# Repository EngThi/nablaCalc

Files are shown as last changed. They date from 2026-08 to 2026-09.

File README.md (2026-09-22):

# ∇Calc

A handheld scientific calculator built around an ESP32-S3, featuring a 2.2-inch SPI display, an OV5640 camera for snapping equations, and a custom 4-layer PCB inside a 3D-printed case.

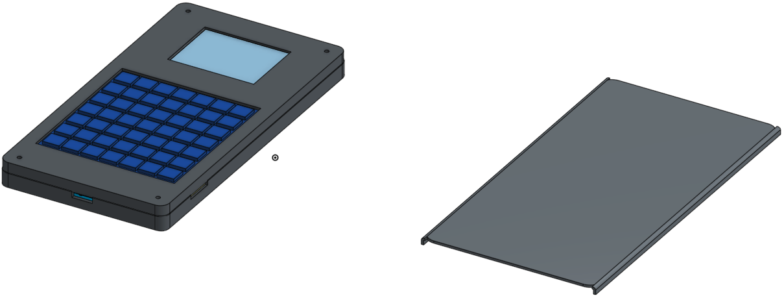
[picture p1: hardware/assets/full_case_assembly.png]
NablaCalc virtual enclosure assembly


## Why I built this

Phones have calculator apps, but pulling out a phone while studying is an immediate distraction. On the other hand, traditional scientific calculators are expensive and lack the modern features and tech we have today.

I wanted to make a dedicated desk tool with modern open hardware (ESP32-S3, USB-C, SPI screen) and physical keys. The camera is tucked behind a sliding shutter just to snap math problems from textbooks or notes when needed.

## Current Status

This is a complete hardware design ready for prototype fabrication:
- **PCB:** Custom 4-layer board (84 × 85 mm) designed in EasyEDA Pro, fully routed and DRC-clean.
- **Case:** Multi-part 3D model designed in Onshape with a sliding camera shutter.
- **Keyboard:** The PCB has the matrix routing and MCP23017 expander for a 7×7 layout. The physical tactile membrane and keymat will be built once the components arrive.
- **Firmware:** ESP-IDF base with I2C and SPI peripheral setup.

## Hardware

- **MCU:** ESP32-S3-WROOM-1-N16R8 (16 MB Flash, 8 MB PSRAM)
- **Display:** 2.2-inch 320×240 TFT LCD (ILI9341 via SPI)
- **Camera:** 5 MP OV5640 autofocus module (DVP) with a mechanical cover
- **Power:** USB-C charging with TP4056 and TPS63001 buck-boost (3.3V rail)
- **Storage:** MicroSD slot (SPI)
- **Keypad:** 7×7 matrix via MCP23017 I2C expander

## First build / prices

I am going with the JLC Top PCBA because I do not have experience soldering the small parts myself. Their minimum gives me five boards and two Top assemblies. I will do the Bottom side later.

| Item | Price (USD) |
|---|---:|
| JLC Top PCBA: 5 PCBs + 2 Top assemblies, with the ESP32-S3 | 86.18 |
| Bottom components for the two boards | 4.43 |
| Battery, camera, display, FPC cables and screws | 24.51 |
| **Funding request, without shipping or taxes** | **115.12** |

The parts list, links and price evidence are in [external parts](hardware/procurement/NablaCalc_External_Parts.csv).

## Links

- [EasyEDA PCB Source](hardware/pcb/source/NablaCalc_PCB.epro2) & [Schematic](hardware/pcb/source/NablaCalc_Schematic.epro2)
- [Fabrication Gerbers & BOM](hardware/pcb/)
- [Onshape 3D Assembly](mechanical/onshape_exports/NablaCalc_Assembly_2.2in_Display.step)
- [Firmware Source](firmware/nabla_firmware/)

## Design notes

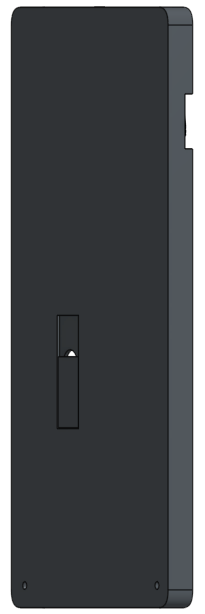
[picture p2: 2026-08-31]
hardware/assets/camera_shutter.png

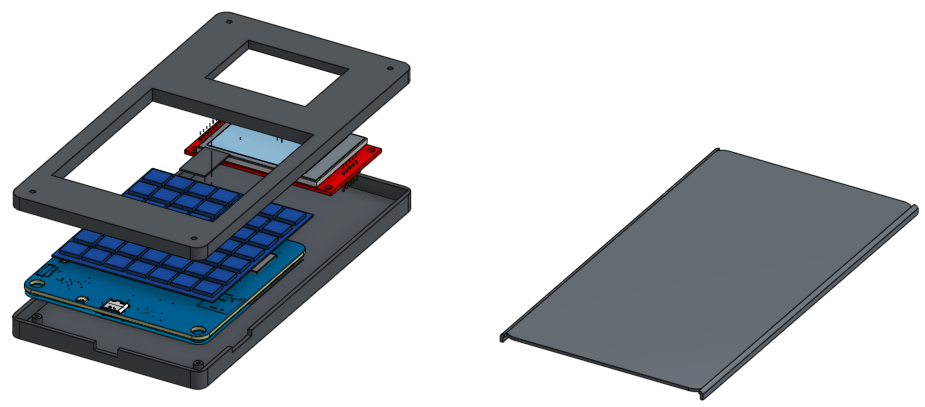
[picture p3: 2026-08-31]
hardware/assets/exploded_view.png

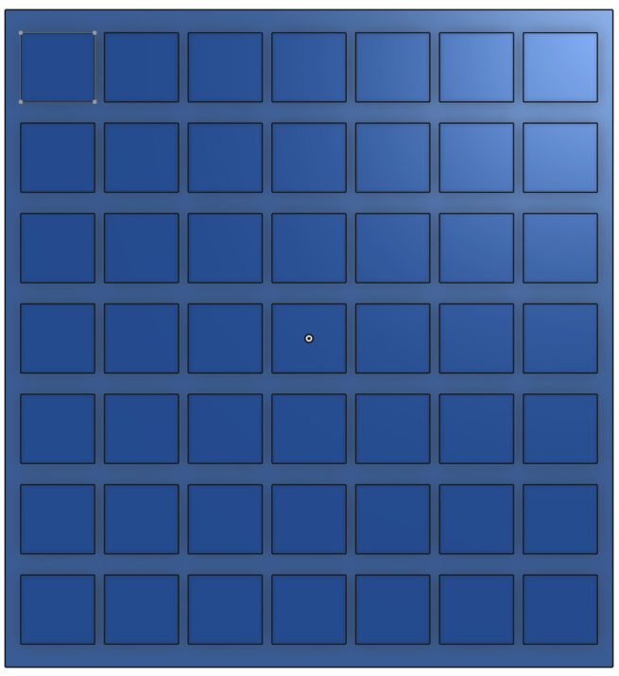
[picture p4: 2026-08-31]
hardware/assets/keypad_case.png

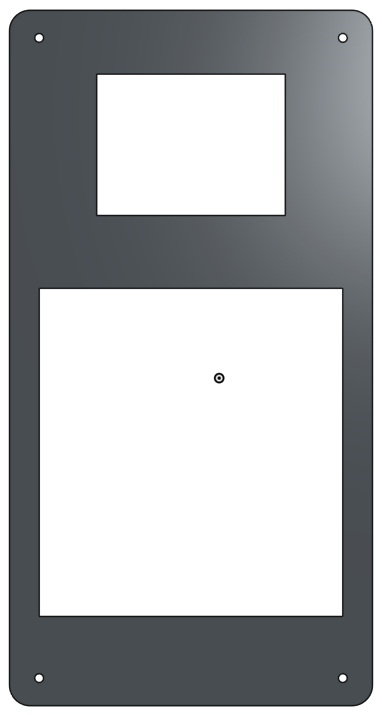
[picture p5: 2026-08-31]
hardware/assets/front_shell_case.png

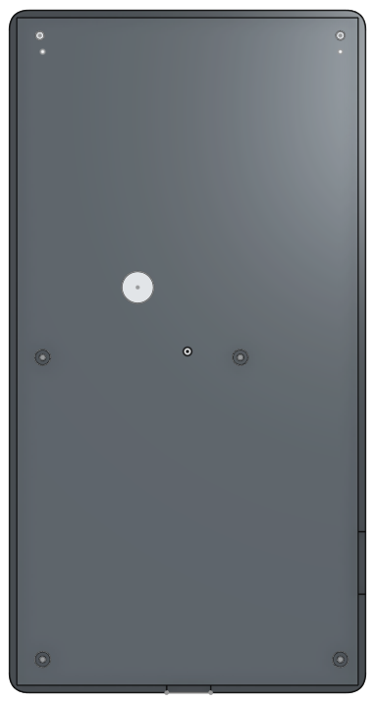
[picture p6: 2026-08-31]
hardware/assets/rear_shell_case.png

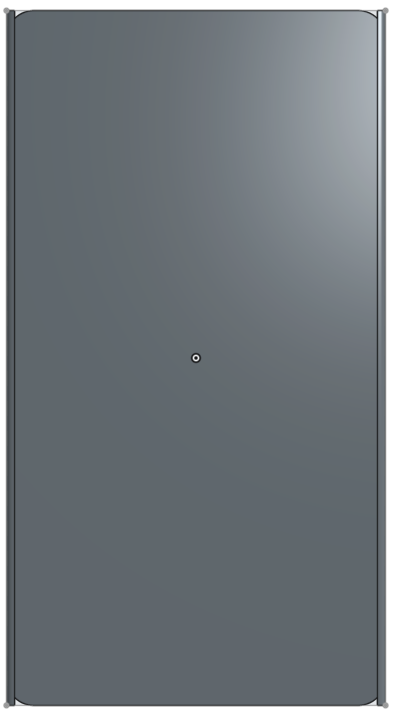
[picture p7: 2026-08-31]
hardware/assets/slide_cover_case.png

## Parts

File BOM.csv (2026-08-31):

Category | Qty | Item | Purchase route | Unit price USD | Line total USD | Included in current request | Status | Source link | Notes
PCB plus Top PCBA | 1 | NablaCalc four-layer PCB with Top SMT | JLCPCB JLCONE quote Y20 | 86.18 | 86.18 | Yes | Confirmed product subtotal | https://jlcpcb.com | Five bare PCBs plus two Top assemblies; includes ESP32-S3 U4.
Bottom-side components | 2 | Manual Bottom population | LCSC | 2.21 | 4.43 | Yes | Reference price for two sets | hardware/procurement/NablaCalc_JLC_LCSC_Only_BOM.csv | For the two JLC Top assemblies.
Battery | 1 | Protected LiPo 1S | Mercado Livre | 6.89 | 6.89 | Yes | Selected | https://www.mercadolivre.com.br/1-peca-503450-37v-com-2-fios-1000mah-5mm-x-34mm-x-50mm/up/MLBU2072595624 | 503450 3.7V 1000mAh; 5 x 34 x 50 mm.
Camera | 1 | RAW autofocus camera | AliExpress | 5.40 | 5.40 | Yes | Selected | https://www.aliexpress.com/item/1005006858943975.html | OV5640 5MP; 24-pin DVP; 68D lens; 78mm FPC.
Display | 1 | SPI LCD module | AliExpress | 6.22 | 6.22 | Yes | Selected | https://www.aliexpress.com/item/33015586094.html | 2.2-inch SPI TFT 320x240; no-touch option.
FPC cables and fasteners | 1 | Interconnect and enclosure hardware | AliExpress | 6.00 | 6.00 | Yes | Selected | https://www.aliexpress.com/item/32845942468.html | Two 14-pin FPC cables, M2 inserts and M2x10mm screws.
Keyboard contact system | 1 | 49-key electrical contact system | TBD |  |  | No | Deferred |  | Decide after checking the physical keymat and modules.
MicroSD | 1 | microSD card | TBD |  |  | No | Deferred |  | Chosen after the first physical build.
Enclosure printing | 1 | Printed case parts | TBD |  |  | No | Deferred |  | Material and print service chosen after physical-module fit.
Shipping and taxes | 1 | Checkout-dependent costs | TBD |  |  | No | Not included |  | The US$115.12 request excludes shipping and taxes.

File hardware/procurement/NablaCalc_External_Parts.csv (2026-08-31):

Category | Qty | Item | Target selection | Unit price USD | Status | Source link | Notes
Battery | 1 | Protected LiPo 1S | 503450 3.7V 1000mAh with PCM | 6.89 | Selected | https://www.mercadolivre.com.br/1-peca-503450-37v-com-2-fios-1000mah-5mm-x-34mm-x-50mm/up/MLBU2072595624 | 5 x 34 x 50 mm; evidence/mercadolivre_battery_503450_brl_37.89.png
Camera | 1 | RAW autofocus camera | OV5640 5MP 24-pin DVP; 68D lens; 78mm FPC | 5.40 | Selected | https://www.aliexpress.com/item/1005006858943975.html | Matches FPC1 24-pin 0.5mm bottom-contact connector.
Display | 1 | SPI LCD module | 2.2-inch SPI TFT 320x240 no-touch option; ILI9341 / MSP2202 | 6.22 | Selected | https://www.aliexpress.com/item/33015586094.html | Evidence: evidence/aliexpress_display_2.2in_no_touch_usd_6.22.png
FPC cables and fasteners | 1 | Interconnect and enclosure hardware | Two 14-pin 0.5mm FPC cables plus M2 inserts and M2x10mm screws | 6.00 | Selected | https://www.aliexpress.com/item/32845942468.html | Does not include the electrical 49-key contact system.
Keyboard contact system | 1 | 49-key electrical contact system | Membrane domes or switches |  | Deferred |  | Choose after checking the physical keymat and modules.
MicroSD | 1 | microSD card | TBD |  | Deferred |  | Choose after the first physical build.
Enclosure printing | 1 | Printed case parts | Front, rear, keymat, shutter and sliding cover |  | Deferred |  | Material and print service chosen after physical-module fit.

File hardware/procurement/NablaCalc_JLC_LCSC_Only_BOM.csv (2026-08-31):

Item | Qty | Designators | Value | Footprint | Device Category | Standardized Description | Manufacturer Part (MPN) | Manufacturer | LCSC Part # | LCSC Product Link
1 | 1 | C1 | 100uF 6.3V | C1206 | Capacitor MLCC | 100uF 6.3V ±20% X5R Multilayer Ceramic Capacitor (MLCC) SMD 1206 | CL31A107MQHNNNE | SAMSUNG | C15008 | https://www.lcsc.com/product-detail/C15008.html
2 | 10 | C2, C11, C12, C13, C14, C15, C16, C17, C18, C25 | 1uF 10V | C0402 | Capacitor MLCC | 1uF 10V ±10% X5R Multilayer Ceramic Capacitor (MLCC) SMD 0402 | CL05A105KP5NNNC | SAMSUNG | C14445 | https://www.lcsc.com/product-detail/C14445.html
3 | 9 | C3, C4, C5, C19, C20, C21, C22, C23, C24 | 100nF 50V | C0603 | Capacitor MLCC | 100nF 50V ±10% X7R Multilayer Ceramic Capacitor (MLCC) SMD 0603 | CL10B104KB8NNNC | SAMSUNG | C1591 | https://www.lcsc.com/product-detail/C1591.html
4 | 5 | C6, C7, C8, C9, C10 | 10uF 25V | C0805 | Capacitor MLCC | 10uF 25V ±10% X5R Multilayer Ceramic Capacitor (MLCC) SMD 0805 | CL21A106KAYNNNE | SAMSUNG | C15850 | https://www.lcsc.com/product-detail/C15850.html
5 | 1 | CARD1 | TF-01A | TF-SMD_TF-01A | Memory Card Connector | MicroSD / TF Card Push-Pull SMT Socket Connector | TF-01A | Korean Hroparts Elec | C91145 | https://www.lcsc.com/product-detail/C91145.html
6 | 1 | CN3 | SM02B-SRSS-TB | CONN-SMD_2P-P1.00 | Battery Connector | JST SH 1.0mm Pitch 2-Pin Side-Entry SMT Shrouded Header (LiPo) | SM02B-SRSS-TB(LF)(SN) | JST | C160402 | https://www.lcsc.com/product-detail/C160402.html
7 | 1 | D1 | B5819W | SOD-123 | Schottky Diode | 40V 1A Surface Mount Schottky Barrier Diode SOD-123 | B5819W | Jingdao Microelectronics | C2685454 | https://www.lcsc.com/product-detail/C2685454.html
8 | 1 | D2 | USBLC6-2SC6 | SOT-23-6 | TVS / ESD Protection | Very Low Capacitance Dual-Line ESD Protection TVS Diode SOT-23-6 | USBLC6-2SC6 | TECH PUBLIC | C2827654 | https://www.lcsc.com/product-detail/C2827654.html
9 | 1 | FPC1 | FH12-24S-0.5SH(55) | FPC-SMD_FH12-24S-0.5SH-55 | FPC Connector (Camera) | 24-Pin 0.5mm Pitch Bottom Contact ZIF FPC Connector (OV5640 DVP) | FH12-24S-0.5SH(55) | Hirose Electric | C202112 | https://www.lcsc.com/product-detail/C202112.html
10 | 2 | FPC2, J_KEY | FH12-14S-0.5SH(55) | FPC-SMD_14P-P0.50 | FPC Connector (Display/Key) | 14-Pin 0.5mm Pitch Bottom Contact ZIF FPC Connector (Display & Keypad) | FH12-14S-0.5SH(55) | Hirose Electric | C5378715 | https://www.lcsc.com/product-detail/C5378715.html
11 | 1 | KEY1 | 6x6x6mm Tactile | SW-SMD_4P-L6.0-W6.0-P4.50 | Tactile Switch | 6.0x6.0x6.0mm SPST-NO SMT Tactile Pushbutton Switch (Boot Mode) | TS-1087-C-W | Domestic Brand | C23550 | https://www.lcsc.com/product-detail/C23550.html
12 | 1 | L1 | 2.2uH 4.5A | IND-SMD_L4.5-W4.1 | Power Inductor | 2.2uH ±20% 4.5A Shielded Power Inductor SMD 4020 (TPS63001) | SRP4020TA-2R2M | BOURNS | C719179 | https://www.lcsc.com/product-detail/C719179.html
13 | 1 | LDO2 | TPS63001DRCR | VSON-10_L3.0-W3.0-P0.50 | Buck-Boost Converter | High-Efficiency Single-Inductor Buck-Boost Converter Fixed 3.3V 1.2A VSON-10 | TPS63001DRCR | Texas Instruments | C28060 | https://www.lcsc.com/product-detail/C28060.html
14 | 1 | Q1 | AO3401A | SOT-23 | P-Channel MOSFET | -30V -4.2A P-Channel Power MOSFET SOT-23 (USB Power-Path Switch) | AO3401A | Alpha & Omega Semiconductor | C15127 | https://www.lcsc.com/product-detail/C15127.html
15 | 6 | R1, R3, R13, R14, R20, R21 | 10kΩ 1% | R0402 | Chip Resistor | 10kΩ ±1% 1/16W Thick Film Chip Resistor SMD 0402 | 0402WGF1002TCE | UNI-ROYAL | C25744 | https://www.lcsc.com/product-detail/C25744.html
16 | 2 | R2, R10 | 33Ω 5% | R0603 | Chip Resistor | 33Ω ±5% 1/10W Thick Film Chip Resistor SMD 0603 (USB Data Matching) | 0603WAF330JT5E | UNI-ROYAL | C23140 | https://www.lcsc.com/product-detail/C23140.html
17 | 1 | R4 | 3kΩ 1% | R0603 | Chip Resistor | 3kΩ ±1% 1/10W Thick Film Chip Resistor SMD 0603 (TP4056 PROG) | 0603WAF3001T5E | UNI-ROYAL | C4211 | https://www.lcsc.com/product-detail/C4211.html
18 | 2 | R5, R6 | 4.7kΩ 1% | R0805 | Chip Resistor | 4.7kΩ ±1% 1/8W Thick Film Chip Resistor SMD 0805 (I2C Bus Pull-Up) | 0805W8F4701T5E | UNI-ROYAL | C17673 | https://www.lcsc.com/product-detail/C17673.html
19 | 2 | R7, R8 | 5.1kΩ 5% | R1206 | Chip Resistor | 5.1kΩ ±5% 1/4W Thick Film Chip Resistor SMD 1206 (USB-C CC1/CC2 Pull-Down) | RMC12065.1K5%N | Tyohm | C269762 | https://www.lcsc.com/product-detail/C269762.html
20 | 6 | R11, R15, R16, R17, R18, R19 | 100kΩ 1% | R0402 | Chip Resistor | 100kΩ ±1% 1/16W Thick Film Chip Resistor SMD 0402 | 0402WGF1003TCE | UNI-ROYAL | C25741 | https://www.lcsc.com/product-detail/C25741.html
21 | 1 | SW1 | TS-1101-C-W | SW-SMD_L6.0-W3.3-LS8.0 | Tactile Switch | 6.0x3.3x2.5mm Side-Actuated SMT Tactile Switch (ESP32 Reset / EN) | TS-1101-C-W | XKB Connection | C318938 | https://www.lcsc.com/product-detail/C318938.html
22 | 1 | U2 | MCP23017-E/ML | QFN-28_L6.0-W6.0-P0.65 | I/O Expander IC | 16-Bit I2C I/O Port Expander with Interrupt Output QFN-28 (Keypad 7x7) | MCP23017-E/ML | Microchip Technology | C639770 | https://www.lcsc.com/product-detail/C639770.html
23 | 1 | U3 | TP4056-42-ESOP8 | ESOP-8_L4.9-W3.9-P1.27 | Battery Charger IC | 1A Standalone Linear Li-Ion / LiPo Battery Charger with Thermal Regulation ESOP-8 | TP4056-42-ESOP8 | TOPPOWER | C16581 | https://www.lcsc.com/product-detail/C16581.html
24 | 1 | U4 | ESP32-S3-WROOM-1-N16R8 | WIRELM-SMD_ESP32-S3 | Wi-Fi & BLE MCU Module | Dual-Core Xtensa LX7 @ 240MHz, 16MB Quad Flash, 8MB Octal PSRAM Module | ESP32-S3-WROOM-1-N16R8 | Espressif Systems | C2913202 | https://www.lcsc.com/product-detail/C2913202.html
25 | 3 | U5, U6, U8 | TLV70028DDCR | SOT-23-5 | LDO Linear Regulator | 200mA Low-Dropout (LDO) Linear Voltage Regulator Fixed 2.8V SOT-23-5 | TLV70028DDCR | Texas Instruments | C507266 | https://www.lcsc.com/product-detail/C507266.html
26 | 1 | U7 | TLV70015DDCR | SOT-23-5 | LDO Linear Regulator | 200mA Low-Dropout (LDO) Linear Voltage Regulator Fixed 1.5V SOT-23-5 (DVDD) | TLV70015DDCR | Texas Instruments | C2865100 | https://www.lcsc.com/product-detail/C2865100.html
27 | 1 | U9 | PCA9306DCTR | SM8_L3.2-W2.9-P0.65 | I2C Level Translator | Dual Bidirectional I2C Bus and SMBus Voltage-Level Translator VSSOP-8 | PCA9306DCTR | Texas Instruments | C123752 | https://www.lcsc.com/product-detail/C123752.html
28 | 2 | U10, U12 | SN74AXC4T245PWR | TSSOP-16_L5.0-W4.4 | Bus Transceiver | 4-Bit Dual-Supply Bus Transceiver with Configurable Level Shifting TSSOP-16 | SN74AXC4T245PWR | Texas Instruments | C2867798 | https://www.lcsc.com/product-detail/C2867798.html
29 | 1 | U11 | SN74AXC8T245PWR | TSSOP-24_L7.8-W4.4 | Bus Transceiver | 8-Bit Dual-Supply Bus Transceiver with Configurable Level Shifting TSSOP-24 (DVP) | SN74AXC8T245PWR | Texas Instruments | C882718 | https://www.lcsc.com/product-detail/C882718.html
30 | 1 | USBC1 | TYPE-C-31-M-12 | USB-C_SMD-TYPE-C-31-M-12 | USB-C Connector | 16-Pin Mid-Mount SMT USB Type-C Receptacle Female Connector | TYPE-C-31-M-12 | Korean Hroparts Elec | C165948 | https://www.lcsc.com/product-detail/C165948.html

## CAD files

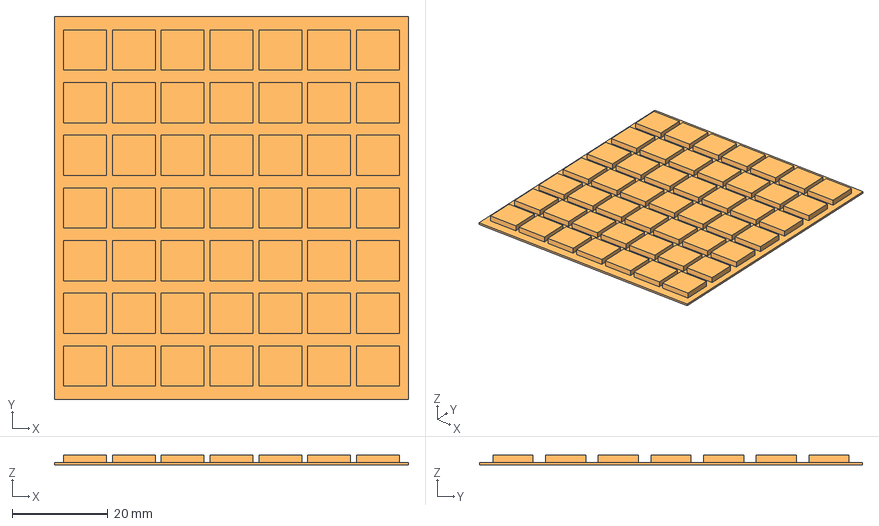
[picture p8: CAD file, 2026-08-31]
mechanical/onshape_exports/NablaCalc_Keymat_7x7.step
74.0 x 80.0 x 2.15 mm

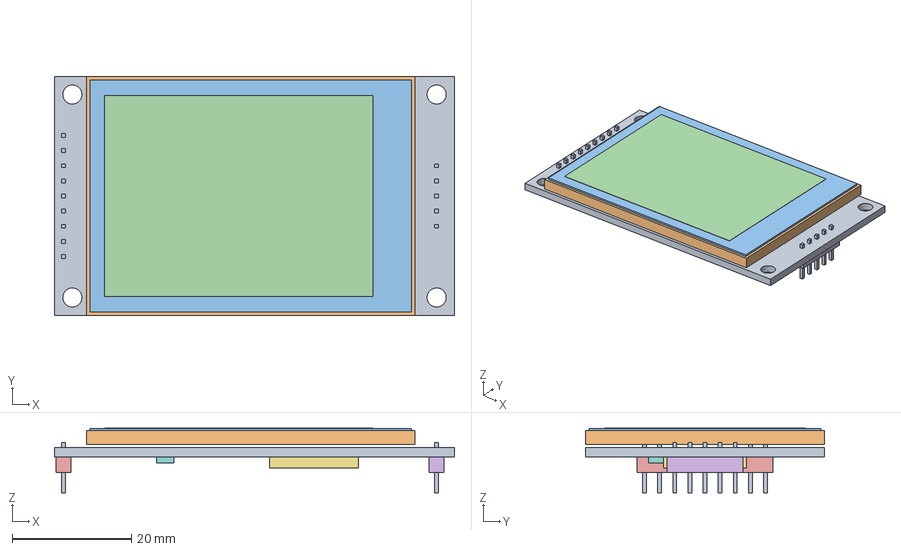
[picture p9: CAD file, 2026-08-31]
mechanical/reference_parts/Display_MSP2202_2.2in.step
67.2 x 40.1 x 10.9 mm

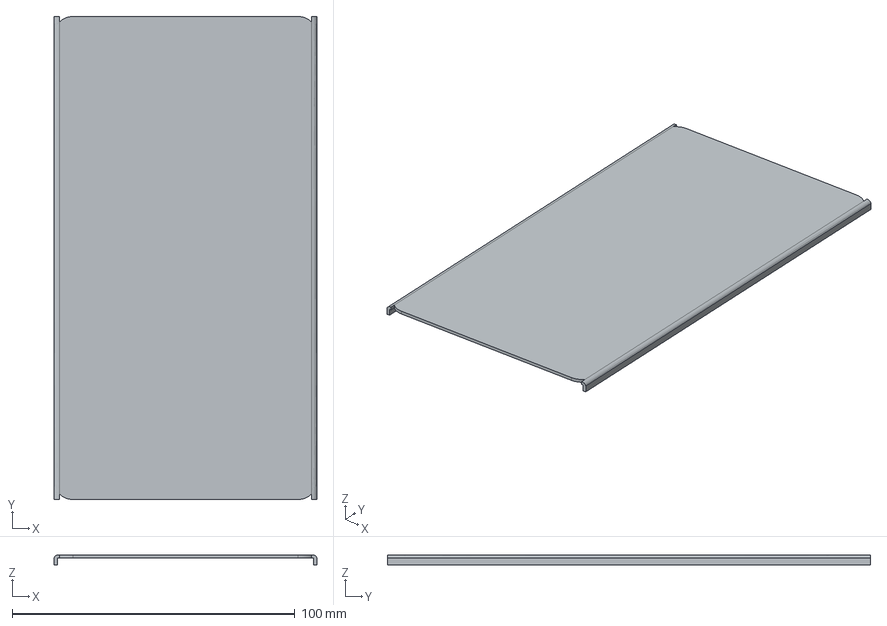
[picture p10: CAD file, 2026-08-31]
mechanical/onshape_exports/NablaCalc_Rear_Sliding_Cover.step
93.1 x 171.0 x 3.70 mm

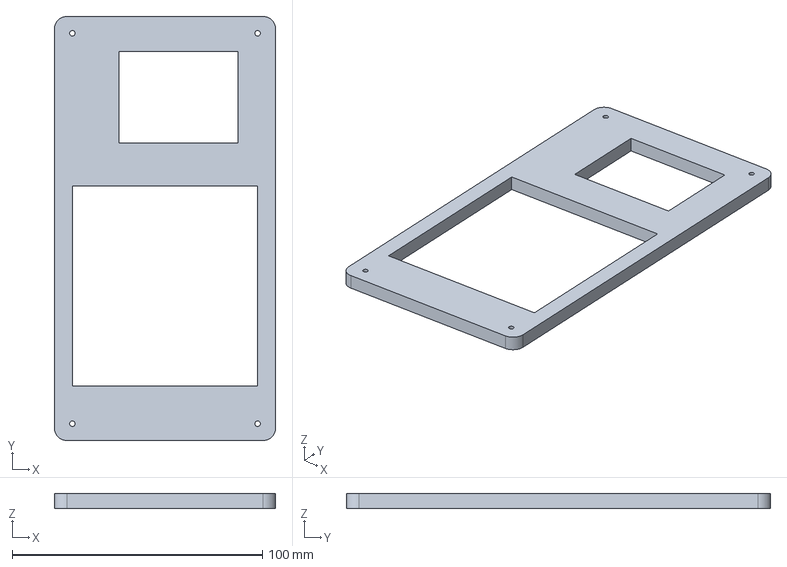
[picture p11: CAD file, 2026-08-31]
mechanical/onshape_exports/NablaCalc_Front_Shell.step
88.4 x 169.4 x 5.80 mm

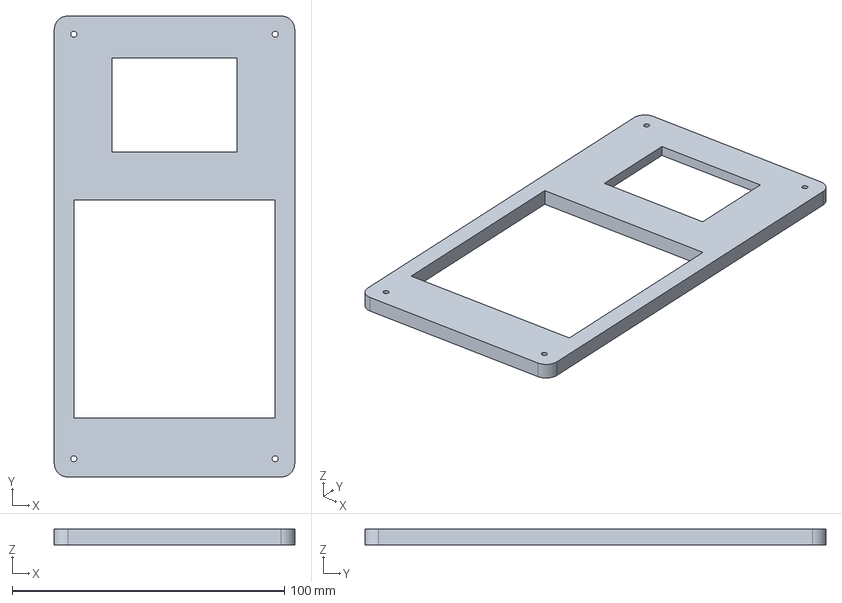
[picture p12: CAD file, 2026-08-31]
mechanical/onshape_exports/NablaCalc_Front_Shell_2.2in_Display.step
88.4 x 169.4 x 5.80 mm

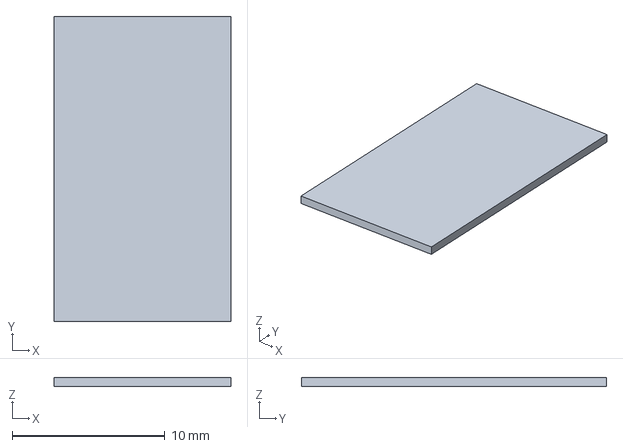
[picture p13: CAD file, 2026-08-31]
mechanical/onshape_exports/NablaCalc_Camera_Privacy_Slider.step
11.6 x 20.0 x 0.6 mm

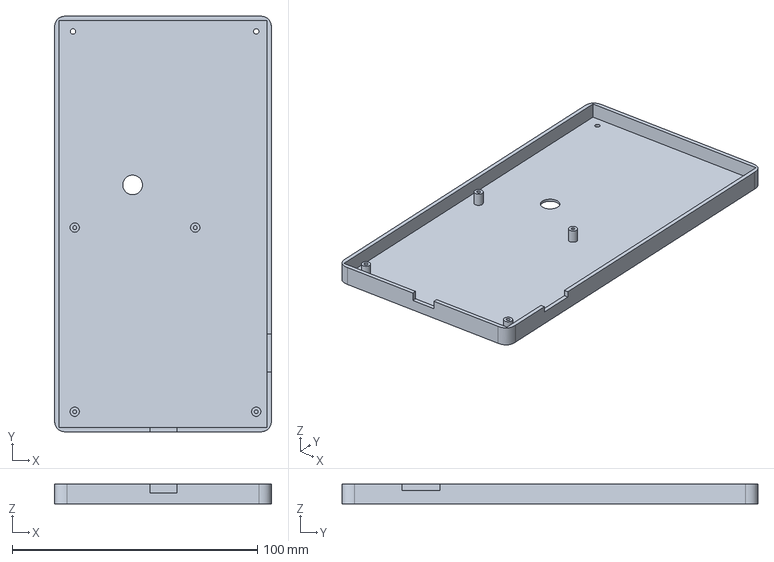
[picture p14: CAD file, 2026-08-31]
mechanical/onshape_exports/NablaCalc_Rear_Shell.step
88.4 x 169.4 x 8.00 mm

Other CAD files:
mechanical/reference_parts/Display_Reference_Legacy.step

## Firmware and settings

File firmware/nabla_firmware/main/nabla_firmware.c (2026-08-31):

#include "board_pins.h"
#include "driver/i2c_master.h"
#include "esp_log.h"
#include "freertos/FreeRTOS.h"
#include "freertos/task.h"
#include "i2c_keypad.h"
#include "nvs_flash.h"
#include <stdio.h>

static const char *TAG = "NABLA_CALC";

static i2c_master_bus_handle_t s_i2c_bus_handle = NULL;

static esp_err_t init_i2c_bus(void) {
  i2c_master_bus_config_t bus_config = {
      .i2c_port = I2C_NUM_0,
      .sda_io_num = I2C_MASTER_SDA_IO,
      .scl_io_num = I2C_MASTER_SCL_IO,
      .clk_source = I2C_CLK_SRC_DEFAULT,
      .glitch_ignore_cnt = 7,
      .flags.enable_internal_pullup = true,
  };

  esp_err_t ret = i2c_new_master_bus(&bus_config, &s_i2c_bus_handle);
  if (ret != ESP_OK) {
    ESP_LOGE(TAG, "Falha ao criar barramento I2C mestre: %s",
             esp_err_to_name(ret));
    return ret;
  }

  ESP_LOGI(TAG, "Barramento I2C mestre inicializado (SDA: GPIO%d, SCL: GPIO%d)",
           I2C_MASTER_SDA_IO, I2C_MASTER_SCL_IO);
  return ESP_OK;
}

static void keypad_task(void *arg) {
  ESP_LOGI(TAG, "Task de Varredura do Teclado 7x7 iniciada com sucesso.");

  while (1) {
    key_code_t key = keypad_scan_once();
    if (key != KEY_NONE) {
      ESP_LOGI(TAG, "[TECLA ACIONADA] Código: %2d | Identificador: %s", key,
               keypad_get_name(key));
    }

    vTaskDelay(pdMS_TO_TICKS(20));
  }
}

void app_main(void) {
  ESP_LOGI(TAG, "=================================================");
  ESP_LOGI(TAG, "  Iniciando ∇Calc Firmware (ESP-IDF / FreeRTOS)  ");
  ESP_LOGI(TAG, "  Alvo: ESP32-S3-WROOM-1-N16R8                   ");
  ESP_LOGI(TAG, "=================================================");

  // 1. Inicializar memória não volátil (NVS)
  esp_err_t ret = nvs_flash_init();
  if (ret == ESP_ERR_NVS_NO_FREE_PAGES ||
      ret == ESP_ERR_NVS_NEW_VERSION_FOUND) {
    ESP_ERROR_CHECK(nvs_flash_erase());
    ret = nvs_flash_init();
  }
  ESP_ERROR_CHECK(ret);

  // 2. Inicializar barramento I2C Mestre
  ESP_ERROR_CHECK(init_i2c_bus());

  // 3. Inicializar expansor de teclado MCP23017
  ret = keypad_init(s_i2c_bus_handle);
  if (ret != ESP_OK) {
    ESP_LOGW(TAG, "Aviso: Expansor MCP23017 não respondeu no endereço 0x20 "
                  "(verifique a placa/alimentação).");
  }

  // 4. Criar Task do FreeRTOS para a varredura do teclado
  xTaskCreatePinnedToCore(keypad_task, "keypad_task", 4096, NULL, 5, NULL, 1);

  ESP_LOGI(TAG, "Sistema pronto e em execução.");
}

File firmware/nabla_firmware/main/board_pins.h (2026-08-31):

#pragma once

#include "driver/gpio.h"

// ============================================================================
// ∇Calc Hardware (ESP32-S3-WROOM-1-N16R8)
// ============================================================================

// I2C Peripherals (MCP23017 Keypad Expander)
#define I2C_MASTER_SDA_IO GPIO_NUM_4
#define I2C_MASTER_SCL_IO GPIO_NUM_5
#define I2C_MASTER_FREQ_HZ 400000 // 400 kHz Fast Mode
#define MCP23017_I2C_ADDR 0x20

// Display SPI (selected MSP2202 / ILI9341 2.2" 320x240 module)
#define LCD_SPI_MOSI GPIO_NUM_21
#define LCD_SPI_MISO GPIO_NUM_3
#define LCD_SPI_SCK GPIO_NUM_47
#define LCD_PIN_CS GPIO_NUM_38
#define LCD_PIN_DC GPIO_NUM_40
#define LCD_PIN_RST GPIO_NUM_41
#define LCD_PIN_BCKL GPIO_NUM_42
// Routed on the main PCB; touch support on the exact seller variant remains unverified.
#define TOUCH_PIN_CS GPIO_NUM_1
#define TOUCH_PIN_IRQ GPIO_NUM_2

// MicroSD Card SPI
#define SD_PIN_CS GPIO_NUM_39

// Camera DVP Interface (OV5640 5MP)
#define CAM_PIN_VSYNC GPIO_NUM_6
#define CAM_PIN_HREF GPIO_NUM_7
#define CAM_PIN_PCLK GPIO_NUM_12
#define CAM_PIN_XCLK GPIO_NUM_15
#define CAM_PIN_D0 GPIO_NUM_10
#define CAM_PIN_D1 GPIO_NUM_14
#define CAM_PIN_D2 GPIO_NUM_8
#define CAM_PIN_D3 GPIO_NUM_9
#define CAM_PIN_D4 GPIO_NUM_11
#define CAM_PIN_D5 GPIO_NUM_18
#define CAM_PIN_D6 GPIO_NUM_17
#define CAM_PIN_D7 GPIO_NUM_16
#define CAM_PIN_RESET GPIO_NUM_13
#define CAM_PIN_PWDN GPIO_NUM_48
#define CAM_PIN_PWR_EN GPIO_NUM_44

// Native USB CDC / JTAG
#define USB_PIN_DM GPIO_NUM_19
#define USB_PIN_DP GPIO_NUM_20

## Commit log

2026-08-31 preparing for submit project
    [3Ddisplay.step, BOM.csv, BOM_PCB2_6_2026-08-22.csv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]
2026-08-31 refine funding budget details
    [NablaCalc_External_Parts.csv]
2026-08-31 organize project BOM files
    [BOM.csv, NablaCalc_External_Parts.csv, NablaCalc_JLC_LCSC_Only_BOM.csv]
2026-10-16 hardware: adiciona sub-placa do teclado, carcaça modular 14mm e cotações da fase 2
